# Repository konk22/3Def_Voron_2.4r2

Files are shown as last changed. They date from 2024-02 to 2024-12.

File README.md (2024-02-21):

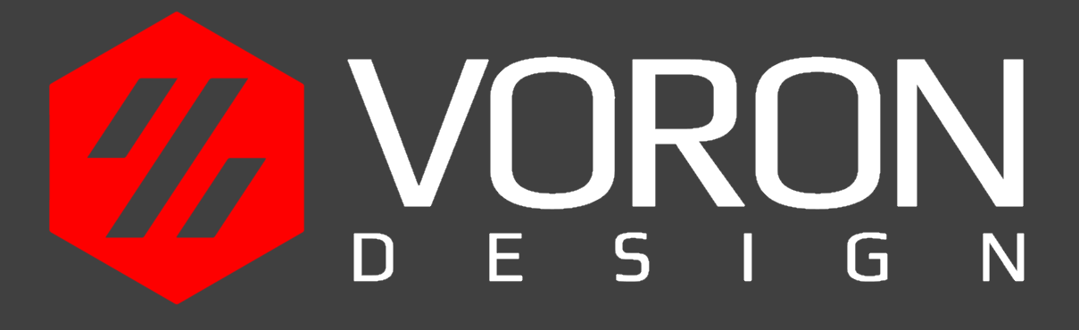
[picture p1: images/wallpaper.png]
  

# Репозиторий является личным сборником систематизированных данных для настройки и доработки принтера Voron 2.4r2 300mm от поставщика 3Def.  
## Все материалы, предоставленные в этом репозитории, являются компиляцией советов, инструкций и примеров конфигураций, полученных из официальных wiki каждого компонента сборки:  

* Комплект для сборки включает в себя:  
	* Voron 2.4r2 300mm;
  	* StealthBurner; 
	* OrangePI Zero 3;  
	* MKS Monster8v2;  
 	* Mellow Fly-SB2040;  
  	* Euclid probe;  
  	* Camera 1080p;  
  	* Display 7 inch, HDMI, LCD 1920x1080, Capacitive Touch Screen;  
  	* BTT Smart Filament Sensor;   
  
* Используемое ПО:  
	* Ubuntu 22.04 jammy server linux6.1.31;
 	* CanBoot;
  	* Klipper;
  	* Mainsail;
  	* KlipperScreen;
  	* Telegram Bot;
  	* Crowsnest;
  	* Mobileraker;
  	* K-ShakeTune  
  
* Дополнения:  
  	* Система очистки сопла;  
  	* Система перемешивания воздуха в камере Nevermore;  
  	* Система вентиляции с угольным фильтром и функции поддержания заданной температуры в камере;

## Исправления, рекомендации, новые подходы к настройке и прочие комментарии прошу оставлять [здесь](https://github.com/konk22/3Def_Voron_2.4r2/discussions/new?category=ideas)

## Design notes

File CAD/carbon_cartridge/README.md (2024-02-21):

# Угольный фильтр для системы вентеляции
* Настройка печати:
  * своев сверху: 0
  * слоев снизу: 0  
  * заполнение: 20%
  * тип заполнения: гироидный  
* После печати необходимо вырезать безворсовую салфетку и проложить ее между прижимом для салфетки и корпусом фильтра, вторую салфетку необходимо проложить между крышкой и вторым прижимом. При необходимости капнуть супер-клей в стык крышки и прижима для салфетки

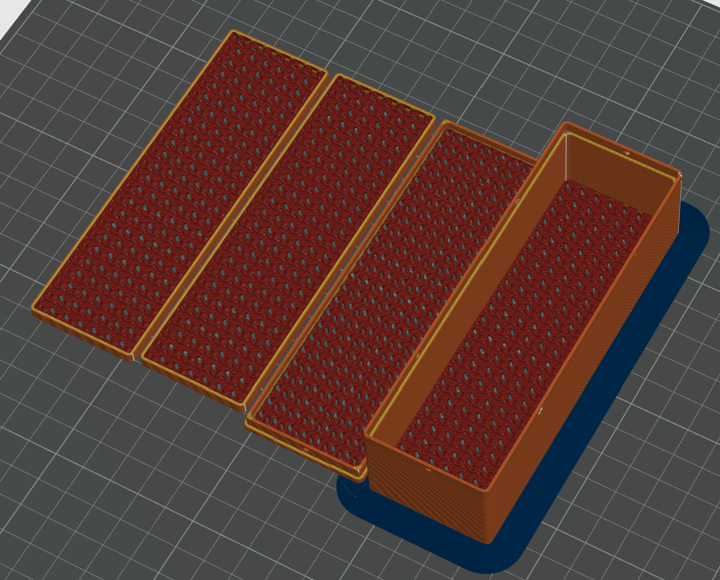
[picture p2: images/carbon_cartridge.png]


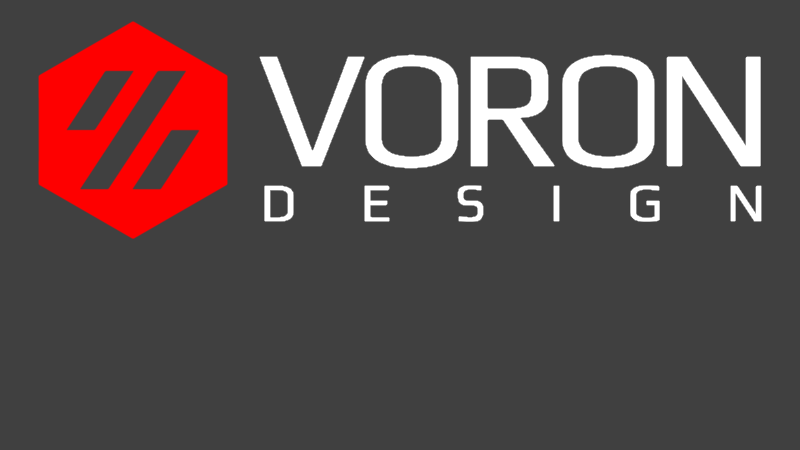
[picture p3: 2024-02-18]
images/watermark800x450.png

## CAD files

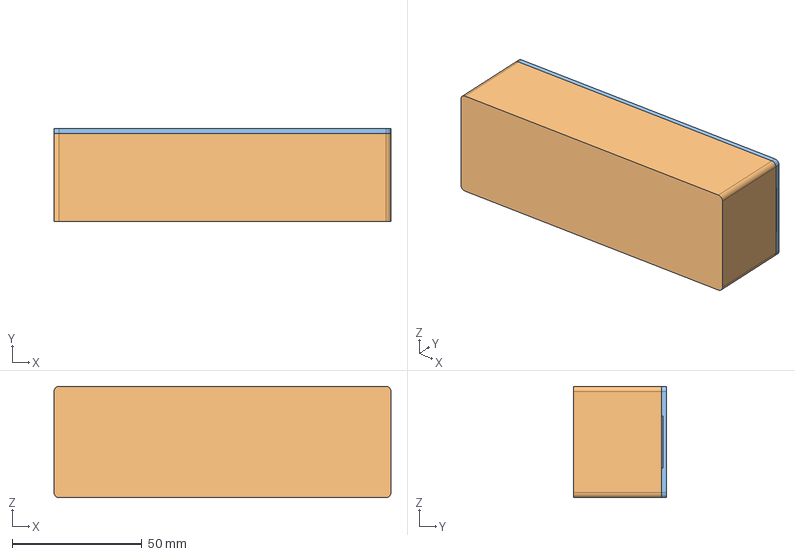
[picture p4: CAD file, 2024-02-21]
CAD/carbon_cartridge/carbon_cartridge.step
130.0 x 36.0 x 43.0 mm
прижим для салфетки
фильтр
Крышка

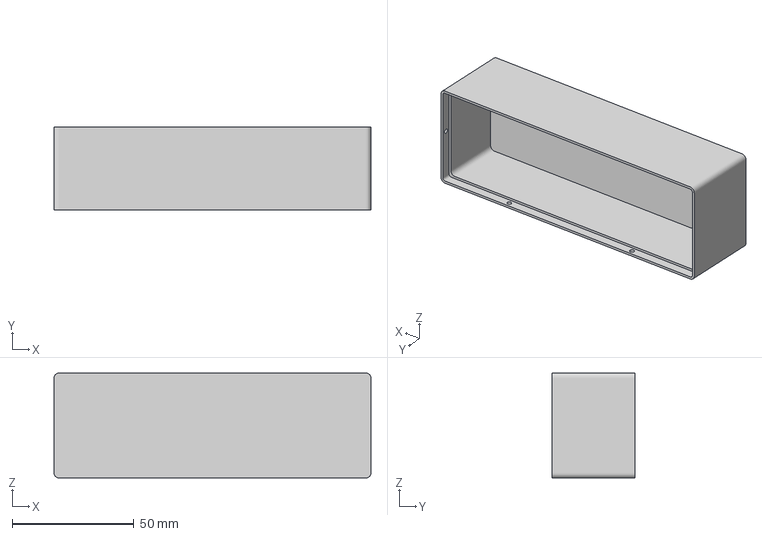
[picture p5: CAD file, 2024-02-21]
CAD/carbon_cartridge/filter.3mf
130.0 x 34.0 x 43.0 mm

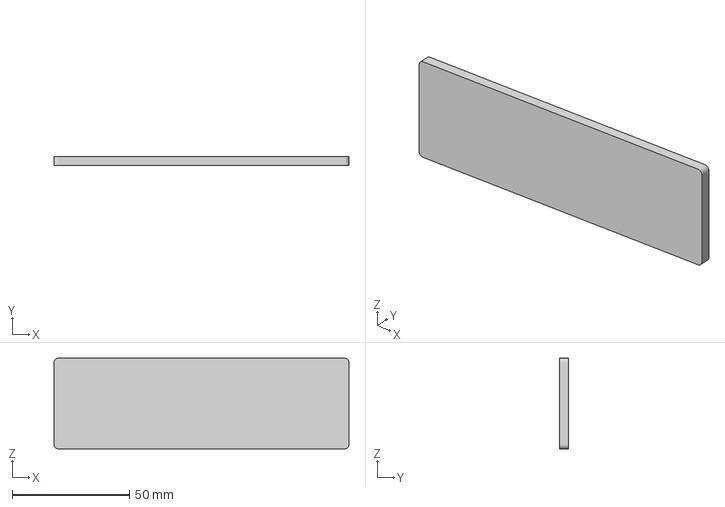
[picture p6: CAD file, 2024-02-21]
CAD/carbon_cartridge/napkin_clamp.3mf
125.6 x 4.00 x 38.6 mm

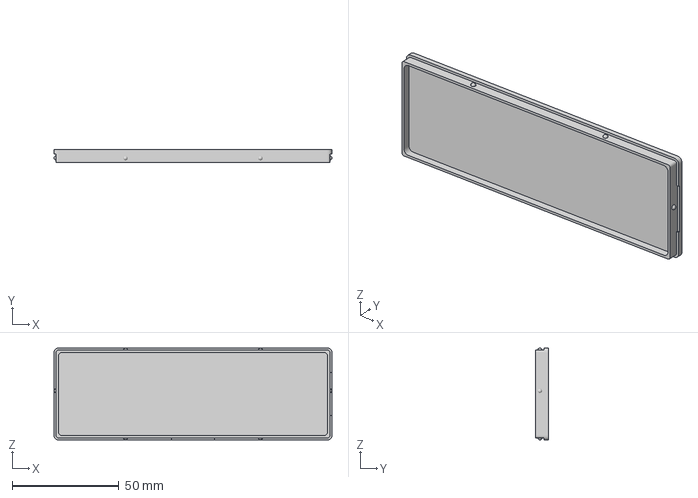
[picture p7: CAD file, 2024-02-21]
CAD/carbon_cartridge/cap.3mf
130.0 x 6.00 x 43.0 mm

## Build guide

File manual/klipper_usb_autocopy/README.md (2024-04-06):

# Klipper USB Autocopy    
This script facilitates the automatic mounting and copying of files from USB drives on a Raspberry Pi system.  

## Functionality  
* **Mounting USB Drives**: When a USB drive is plugged in, the script automatically detects it and mounts it to the system.  
* **Copying Files**: Once mounted, the script identifies specified file patterns (e.g., *.gcode) on the USB drive and copies them to a designated destination directory. If no matching files are found, the script exports files from the destination directory to the USB drive.  
* **Unmounting USB Drives**: When a USB drive is removed, the script unmounts it from the system and removes any associated mount points.  
* **Notification**: Upon completion of the copying process, a short beep is emitted. This requires the "beeper" to be declared in Klipper configuration.    
  
## Installation  
This script can be installed using the install.sh script by executing the following command:  
```  
wget -O - https://raw.githubusercontent.com/konk22/3Def_Voron_2.4r2/main/manual/klipper_usb_autocopy/install.sh | bash
```  
Ensure that you have necessary permissions and review the script before executing it on your system.  

For detailed information on how the script works, refer to the comments within the script file.  

Inspired by the project: https://github.com/DrumClock/mount_copy/tree/main

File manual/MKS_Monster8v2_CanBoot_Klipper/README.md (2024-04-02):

## Установка на MKS Monster8v2 CanBoot и прошивки Klipper:  

* Устанавливаем CanBoot:  
  ```
  cd ~
  git clone https://github.com/Arksine/katapult
  ```  
* Устанавливаем Pyserial:  
  ```
  pip3 install pyserial
  ```  
* Выключаем принтер от сети 220, затем переводим плату MKS Monster8v2 в режим DFU:  
    * Ставим перемычку в блоке "select" (зеленый квадрат, замкнута левая группа контактов);  
    * Ставим перемычку питания платы в положение "On" (красный квадрат, замкнуты верхние контакты);  
    * Подключаем питание Orangepi Zero 3 к внешнему источнику питания, например зарядка для телефона или повербанк. К сети 220 принтер не подключаем!!!  
    * Зажимаем кнопки Reset и Boot. Отпускаем сначала Reset, затем Boot  

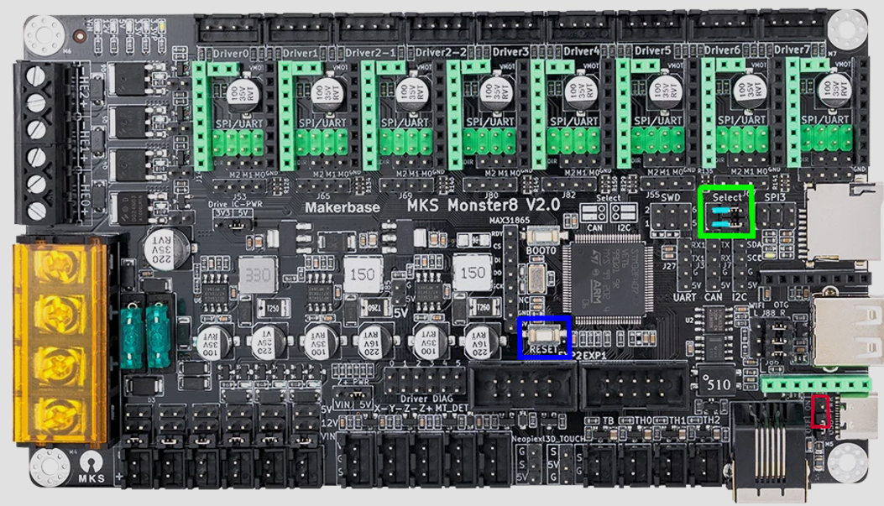
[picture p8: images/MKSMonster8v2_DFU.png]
  
  
* Подключаемся через SSH к Orangepi Zero 3, и проверяем подключился ли MCU. В ответ должны получить ```STMicroelectronics STM Device in DFU mode```:  
    
    
* Компилируем прошивку CanBoot для MKS Monster8v2:  
  ```
  cd katapult
  make menuconfig
  ```  
* Выставляем настройки как на картинке:  

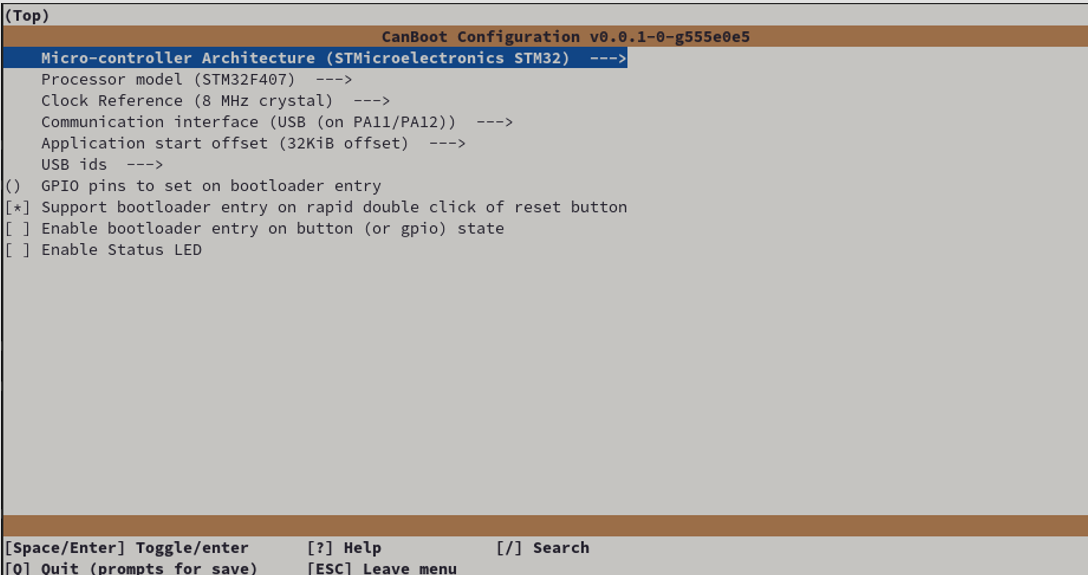
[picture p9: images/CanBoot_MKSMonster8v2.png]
    

* Компилируем:  
  ```
  make clean
  make
  ```  
* Прошиваем CanBoot в MKS Monster8v2. ПРИМЕЧАНИЕ. Если после вышеизложенного вы видите ошибку, не волнуйтесь, все в порядке, если у вас есть надпись «Файл загружен успешно» в строке перед ошибкой:  
  ```
  sudo dfu-util -a 0 -D ~/katapult/out/katapult.bin --dfuse-address 0x08000000:force:mass-erase:leave -d 0483:df11
  ```  
* Проверяем загружен ли CanBoot. Дважды нажимаем Reset, затем вводим команды:  
  ```
  lsusb
  	# в ответ должны получить OpenMoko stm32f407xx
  ls /dev/serial/by-id/
  	# в ответ должны получить серийный номер устройства /dev/serial/by-id/usb-katapult_stm32f407xx_<серийный номер>-if00
  ПРИМЕЧАНИЕ: /dev/serial/by-id/usb-katapult_stm32f407xx_<серийный номер>-if00 необходим для следующих шагов
  ```  
* Компилируем прошивку Klipper для Monster8v2:  
  ```
  cd ~/klipper
  make menuconfig
  ```  
* Выставляем настройки как на картинке:

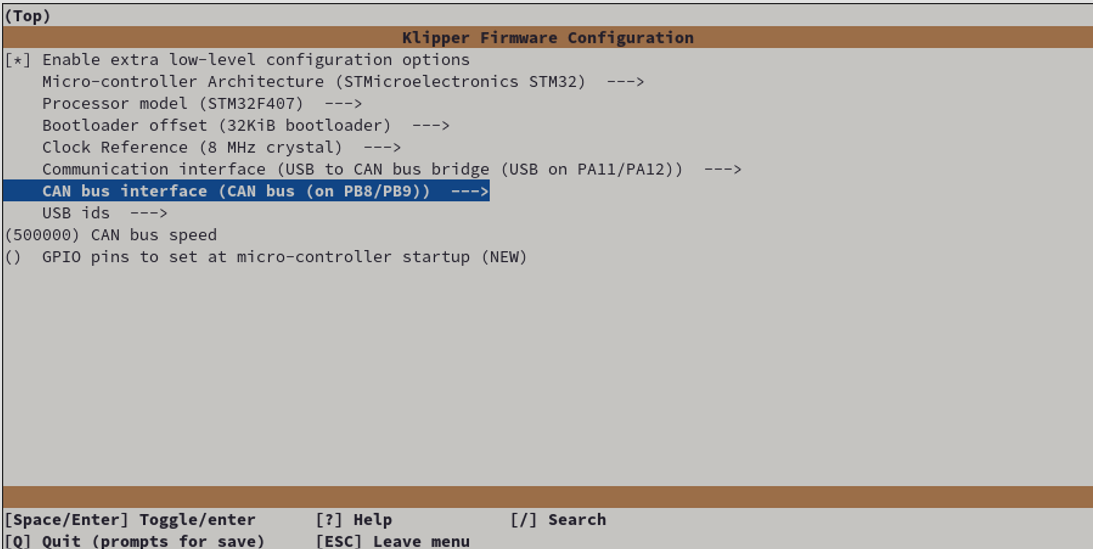
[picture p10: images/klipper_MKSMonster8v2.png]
  
      
* Компилируем:  
  ```
  make clean
  make
  ```  
* Прошиваем MKS Monster8v2 только что скомпилированной прошивкой Klipper через katapult:  
  ```
  python3 ~/katapult/scripts/flash_can.py -d  /dev/serial/by-id/usb-CanBoot_stm32f407xx_<серийный номер>-if00
  ```  

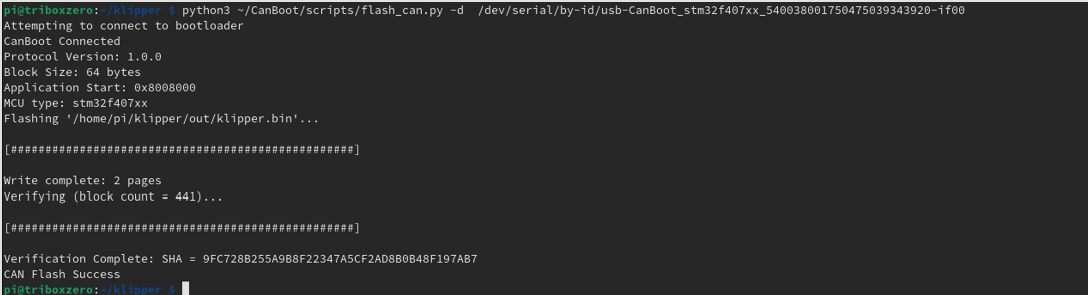
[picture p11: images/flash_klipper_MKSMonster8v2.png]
  
    
* Настраиваем интерфейс CAN0 на Orangepi Zero 3. Создадим файл интерфейса:  
  ```
  sudo nano /etc/network/interfaces.d/can0
  ```  
* Запишем настройки интерфейса в файл:  
  ```
  allow-hotplug can0
  iface can0 can static
	 bitrate 500000
	 up ifconfig $IFACE txqueuelen 256
	 pre-up ip link set can0 type can bitrate 500000
	 pre-up ip link set can0 txqueuelen 256

  ```  
* Перезагружаем:  
  ```
  sudo reboot
  ```  
* Проверяем установлена ли связь с MKS Monster8v2 после прошивки. В ответе должна быть строка с ```1b50:606f OpenMoko```:  
  ```
  lsusb
  ```  

    

* Отключаем внешнее питание от orangepi. Ставим перемычку питания платы в положение "Off" (красный квадрат, замкнуты нижние контакты):  
   
    
  
* Подключаем питание 220 к принтеру и проверяем видит ли Orangepi Zero 3 наш MKS Monster8v2:  
  ```
  ~/katapult/scripts/flash_can.py -i can0 -q
  ```  

    

* Проверяем работает ли интерфейс CAN0:  

    

* Получаем UUID MKS Monster8v2. ПРИМЕЧАНИЕ: Команда возвращает UUID только для неинициализарованных MCU в Klipper (printer.cfg):  
  ```
  ~/katapult/scripts/flash_can.py -i can0 -q
  ```  
    
    
* Для инициализируем MSU в printer.cfg, добавим данные строки:  
  ```
  [mcu]
  canbus_uuid: <ВСТАВИТЬ UUID>
  ```
* Проверяем раздел ```Настройки->Системная информация``` Mainsail. Должен появиться ```mcu (stm32f407xx)```, а так же версии прошивок ```host (aarch64, 64bit)``` и ```mcu (stm32f407xx)``` должны быть одинаковые:  

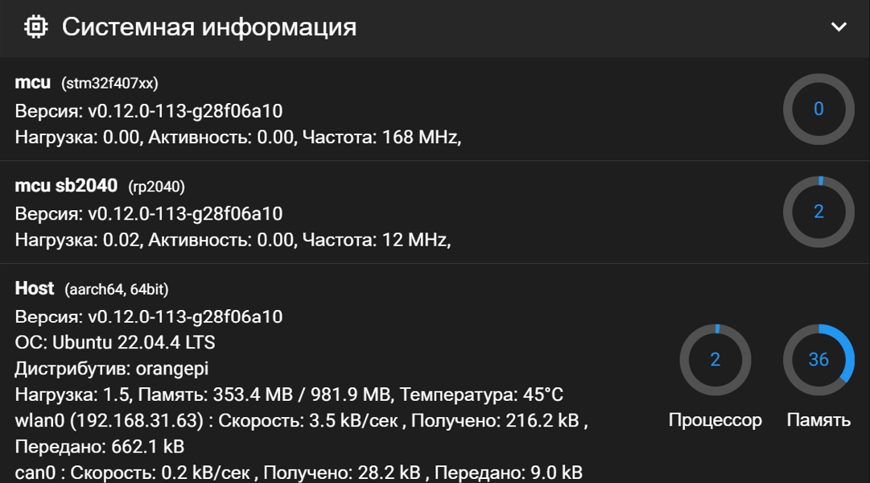
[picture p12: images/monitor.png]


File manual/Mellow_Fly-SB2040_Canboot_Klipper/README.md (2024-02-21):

## Установка CanBoot и прошивка Klipper для Mellow Fly-SB2040:  

* Подготавливаем Mellow Fly-SB2040 к прошивке:  
	* Выключаем принтер от сети 220;  
	* Отключаем CAN проводку от модуля Fly-SB2040;  
	* Подключаем кабель Type-c к порту orangepi Zero 3;  
 	* Подключаем питание 220 к принтеру;  
	* Зажимаем кнопку Boot на Fly-SB2040;  
	* Подключаем провод Type-c к модулю Fly-SB2040 и отпускаем кнопку Boot;  
	* Подключаемся к принтеру по ssh  
* Компилируем прошивку CanBoot для Mellow Fly-SB2040:  
  ```
  cd ~/CanBoot
  make menuconfig
  ```  
* Выставляем настройки как на картинке:  
  
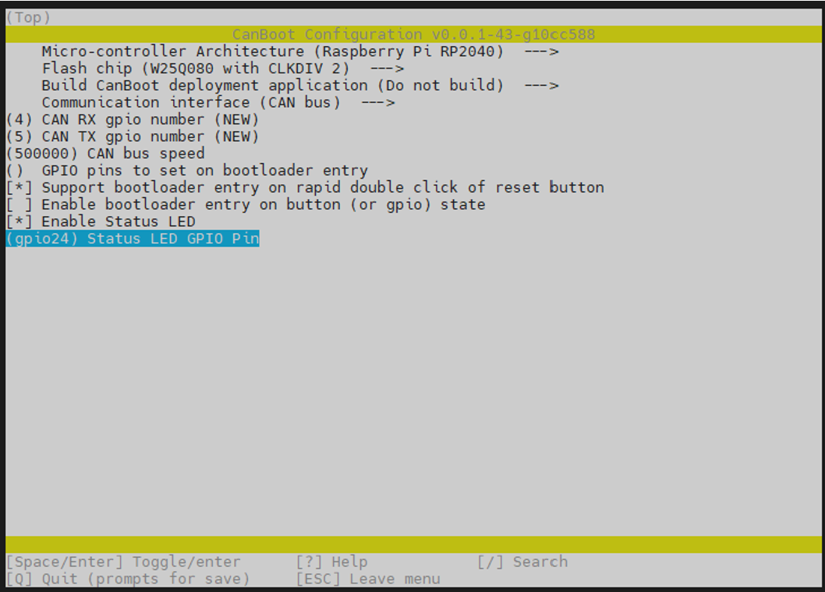
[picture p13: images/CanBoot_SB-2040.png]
  

* Компилируем:  
  ```
  make clean
  make -j4
  ```  
* Проверяем подключение Fly-SB2040 к Orangepi Zero 3. В ответе должна быть строка ```Bus 006 Device 002: ID 2e8a:0003 Raspberry Pi RP2 Boot```:  
  ```
  lsusb
  ```  
* Прошиваем Fly-SB2040 только что скомпилированной прошивкой CanBoot:  
  ```
  cd ~/CanBoot
  make flash FLASH_DEVICE=2e8a:0003
  ```  
* Если не настраивали ранее, то добавляем интерфейс CAN0 на Orangepi Zero 3. Создадим файл интерфейса:  
  ```
  sudo nano /etc/network/interfaces.d/can0
  ```  
* Запишем настройки интерфейса в файл:  
  ```
  allow-hotplug can0
  iface can0 can static
	 bitrate 500000
	 up ifconfig $IFACE txqueuelen 256
	 pre-up ip link set can0 type can bitrate 500000
	 pre-up ip link set can0 txqueuelen 256

  ```  
* Перезагружаем:  
  ```
  sudo reboot
  ```  
* Компилируем прошивку Klipper для Fly-SB2040  
  ```
  cd ~/
  ./kiauh/kiauh.sh
  ```  
* Выставляем настройки как на картинке:  

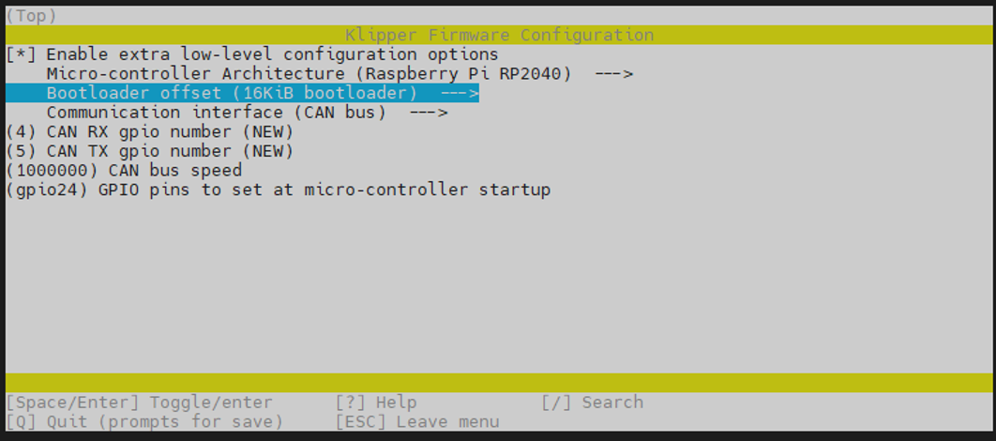
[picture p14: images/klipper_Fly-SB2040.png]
    

* Прошиваем Fly-SB2040 только что скомпилированной прошивкой Klipper. Дожидаемся надписи ```CAN Flash Success ``` как показано на картинке ниже:  
  ```
  python3 ~/klipper/lib/canboot/flash_can.py -u <UUID-Fly-SB2040>
  ```  

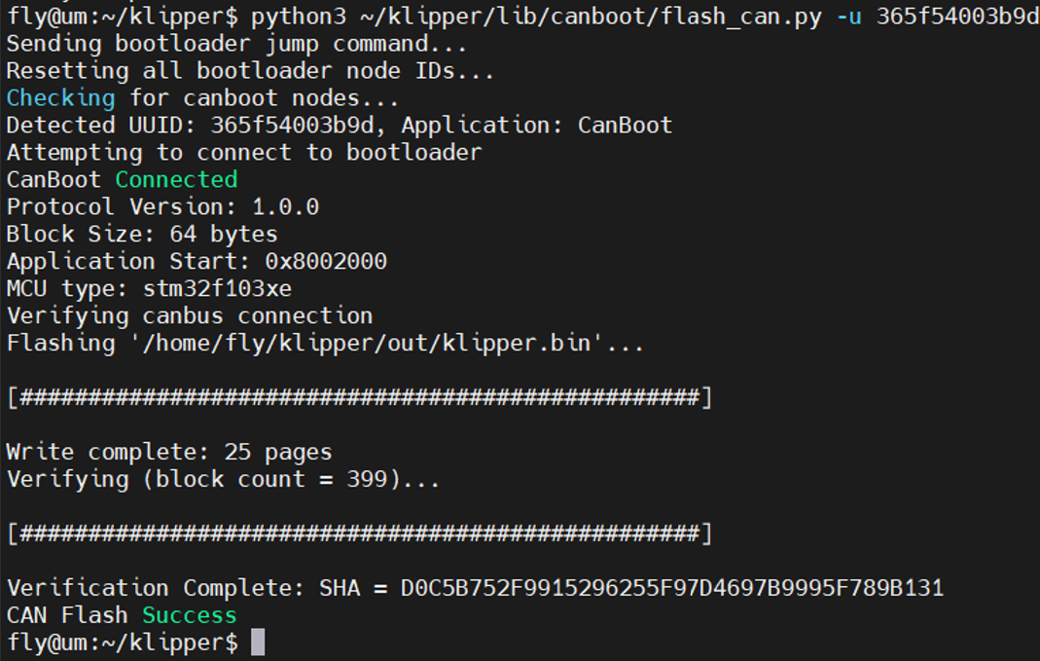
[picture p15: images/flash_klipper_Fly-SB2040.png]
    

* Проверяем раздел ```Настройки->Системная информация``` Mainsail. Должен появиться ```mcu sb2040(rp2040)```, а так же версии прошивок ```host (aarch64, 64bit)``` и ```mcu sb2040(rp2040)``` должны быть одинаковые:    



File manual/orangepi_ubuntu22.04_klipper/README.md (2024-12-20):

# Инструкция по подготовке дистрибутива Ubuntu 22.04 и установке Klipper на Orangepi Zero 3 

* Для установки потребуется скачать дистрибутив Ubuntu 22.04 для Orangepi Zero 3:  
  ```
  http://www.orangepi.org/html/hardWare/computerAndMicrocontrollers/service-and-support/Orange-Pi-Zero-3.html
  ```  
* Записать его на SD карту:  
  * Для Windows: с помощью программы ```Rufus``` или ```BalenaEtcher```  
  * Linux или Mac: ```BalenaEtcher```  
    Подробная инструкция: [KlipperWiki](https://klipper.wiki/ru/home/initial/base#prepare_orange_flash)  
* Установить SD карту в Orangepi Zero 3, подключить клавиатуру и монитор (KlipperScreen HDMI)  
  * Подключаем Orangepi Zero 3 к WIFI.  
        Вводим команду: ```nmtui```  
        Выбираем ```Activate a connections```  
        Подключаемся к своей домашней WIFI сети  
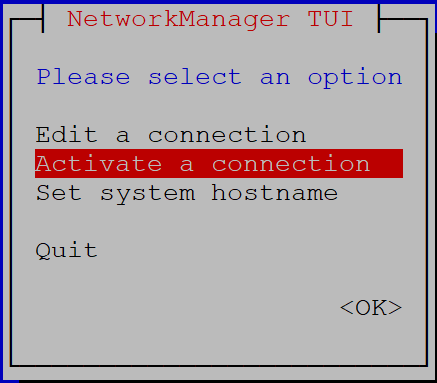
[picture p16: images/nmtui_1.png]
        
    
* Клавиатуру можно отключать, она больше не понадобится  
* Подключаемся к Orangepi Zero 3 по SSH с помощью PuTTY  
* Переходим в пользователя root. Пароль ```orangepi```:  
  ```
  su
  ```  
* Меняем пароль для пользователя root:  
  ```
  passwd
  ```  
* Создаем пользователя ```pi```:  
  ```
  sudo adduser pi
  ```  
* Настраиваем права пользователю аналогично пользователя orangepi:  
  ```
  sudo usermod -aG tty,disk,dialout,sudo,audio,video,plugdev,games,users,systemd-journal,input,netdev pi
  ```  
* Меняем пользователя для автовхода. Меняем ```--autologin orangepi``` на ```--autologin pi```:  
  ```
  sudo nano /lib/systemd/system/getty@.service.d/override.conf
  ```  
* Перезагружаем Orangepi Zero 3. Снова подключаемся через SSH с учетными данными ```pi``` и снова переходим в пользователя root:  
  ```
  reboot
  su
  ```  
* Удаляем пользователя ```orangepi```:  
  ```
  sudo killall -9 -u orangepi && sudo deluser --remove-all-files orangepi
  ```  
* Настраиваем поведение sudo. Меняем строку ```%sudo   ALL=(ALL:ALL) ALL``` на строку ```%sudo   ALL=NOPASSWD: ALL```:  
  ```
  sudo EDITOR=nano visudo
  ```  
* Снова перезагружаем и подключаемся через SSH под пользователем pi:  
  ```
  reboot
  ```  
* Проверяем удален ли пользователь orangepi. Повторяем процедуру удаления если пользователь удален не полностью:  
  ```
  ls /home
  папки orangepi не должно быть в ответе
  su orangepi
  user orangepi does not exist or the user entry does not contain all the required fields
  ```
* Отключим поддержку ipv6:
  ```
  sudo nano /etc/sysctl.conf
  ```
  * Добавим в конец файла:
    ```
    net.ipv6.conf.all.disable_ipv6 = 1
    net.ipv6.conf.default.disable_ipv6 = 1
    net.ipv6.conf.lo.disable_ipv6 = 1
    ```
* Отключим китайские репозитории и добавим глобальные:  
  ```
  sudo nano /etc/apt/sources.list
  ```  
  * Закомментируем все строки и в конец добавим следующее:  
    ```
    deb http://ports.ubuntu.com/ jammy main restricted universe multiverse
    #deb-src http://ports.ubuntu.com/ jammy main restricted universe multiverse
  
    deb http://ports.ubuntu.com/ jammy-security main restricted universe multiverse
    #deb-src http://ports.ubuntu.com/ jammy-security main restricted universe multiverse
  
    deb http://ports.ubuntu.com/ jammy-updates main restricted universe multiverse
    #deb-src http://ports.ubuntu.com/ jammy-updates main restricted universe multiverse
  
    deb http://ports.ubuntu.com/ jammy-backports main restricted universe multiverse
    #deb-src http://ports.ubuntu.com/ jammy-backports main restricted universe multiverse
    ```  
* Отключим китайский репозиторий docker. Закомментируем все записи в файле:  
  ```
  sudo nano /etc/apt/sources.list.d/docker.list
  ```  
* Добавим глобальный репозиторий docker:  
  ```
  sudo curl -fsSL https://download.docker.com/linux/ubuntu/gpg -o /etc/apt/keyrings/docker.asc
  sudo chmod a+r /etc/apt/keyrings/docker.asc
  echo \
  "deb [arch=$(dpkg --print-architecture) signed-by=/etc/apt/keyrings/docker.asc] https://download.docker.com/linux/ubuntu \
  $(. /etc/os-release && echo "$VERSION_CODENAME") stable" | \
  sudo tee /etc/apt/sources.list.d/docker.list > /dev/null
  ```  
* Обновим систему. Ошибок и предупреждений не должно быть:  
  ```
  sudo apt update && sudo apt dist-upgrade -y
  ```  
* Установим пакеты необходимые для работы KlipperScreen:  
  ```
  sudo apt install xorg xinit xserver-xorg-legacy libjpeg-dev zlib1g-dev python3-pip python3-dev libatlas-base-dev python3-gi-cairo python3-virtualenv gir1.2-gtk-3.0 virtualenv matchbox-keyboard wireless-tools xdotool xinput x11-xserver-utils libopenjp2-7 python3-distutils python3-gi python3-setuptools python3-wheel python3-can
  pip3 install vext
  pip3 install vext.gi
  ```  
* Меняем имя хоста. Я выбрал имя ```Voron```:  
  ```
  hostnamectl set-hostname Voron
  ```  
* Удаляем логотип загрузки Ubuntu:  
  ```
  sudo rm /usr/share/plymouth/themes/spinner/bgrt-fallback.png
  sudo rm /usr/share/plymouth/ubuntu-logo.png
  ```  
* Подготавливаем свой логотип в формате png с прозрачным фоном, размер 800x450, изображение должно быть немного выше середины картинки, или копируем логотип из предложенного примера в домашнюю директорию, а затем перемещаем в директорию темы по умолчанию:  
  ```
  sudo wget https://raw.githubusercontent.com/konk22/3Def_Voron_2.4r2/main/images/watermark800x450.png 
  sudo cp /home/pi/watermark800x450.png /usr/share/plymouth/themes/spinner/watermark.png
  ```  
* Копируем логотип загрузки системы в директорию plymouth:  
  ```
  sudo cp /home/pi/watermark800x450.png /usr/share/plymouth/ubuntu-logo.png
  ```  
* Обновим конфигурацию Plymouth и initramfs:  
  ```
  sudo update-initramfs -u
  ```  
* Если в процессе загрузки Orangepi Zero 3 необходимо увидеть лог загрузки, то необходимо на клавиатуре нажать F8.  
* Включим boot splash screen. Необходимо заменить ```bootlogo=false``` на ```bootlogo=true``` и в конец файла добавить строку ```extraargs="console=tty3 consoleblank=0 loglevel=1 quiet splash"```:  
  ```
  sudo nano /boot/orangepiEnv.txt
  ```  
* Для правильной работы KlipperScreen необходимо добавить следующую строку в конфиг xorg:  
  ```
  sudo bash -c "echo needs_root_rights=yes>>/etc/X11/Xwrapper.config"
  ```
* Отключаем ненужные службы для ускорения загрузки. ПРИМЕЧАНИЕ: если используется bluetooth, то ```bluetooth.service``` необходимо удалить из команд:
  ```
  sudo apt-get remove networkd-dispatcher
  sudo systemctl stop systemd-networkd.service dnsmasq.service lircd.service containerd.service bluetooth.service
  sudo systemctl disable systemd-networkd.service dnsmasq.service lircd.service containerd.service bluetooth.service
  ```  
* Перезагружаем:  
  ```
  sudo reboot
  ```  
* Установим git:  
  ```
  sudo apt-get update && sudo apt-get install git -y
  ```  
* Скачиваем Kiauh и переходим в директорию Kiauh:  
  ```
  cd ~ && git clone https://github.com/dw-0/kiauh.git
  ```
* Запускаем скрипт Kiauh:  
  ```
  ./kiauh/kiauh.sh
  ```  
* Вас встретит следующее окно. Нажимаем ```1```, затем устанавливаем по очереди: Klipper, Moonraker, Mainsail, KlipperScreen, Telegram Bot, Crowsnest, Mobileraker:  
   
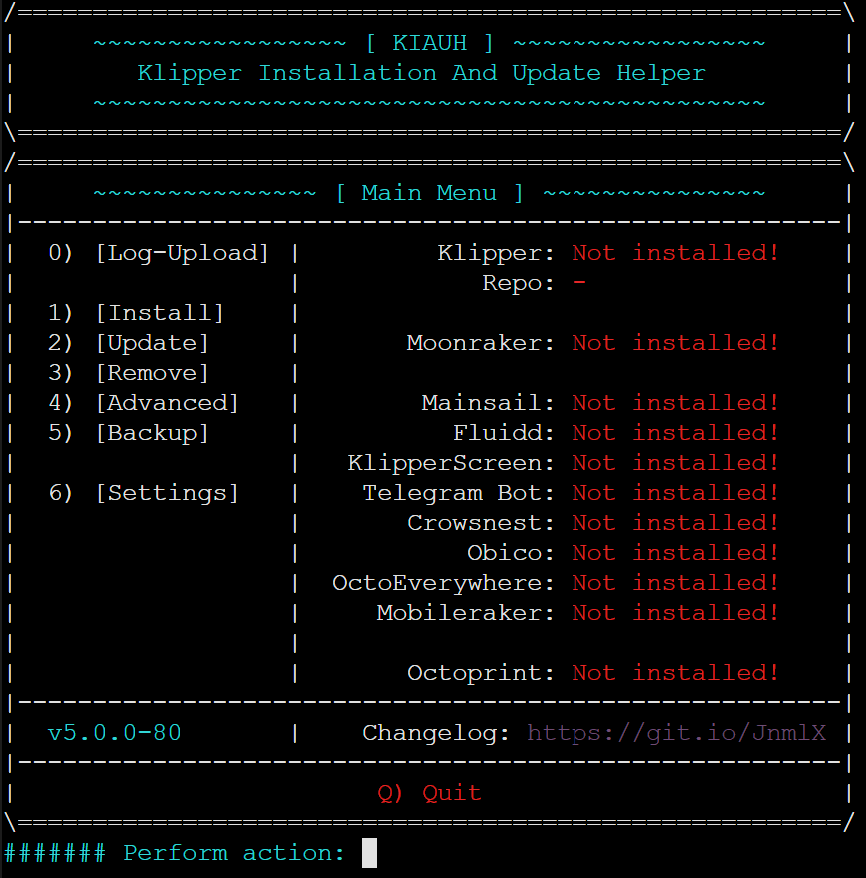
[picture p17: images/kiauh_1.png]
    
    
    
    
* После установки всех пакетов нажимаем ```B``` и выходим на начальное окно. Оно должно выглядеть так:  
    
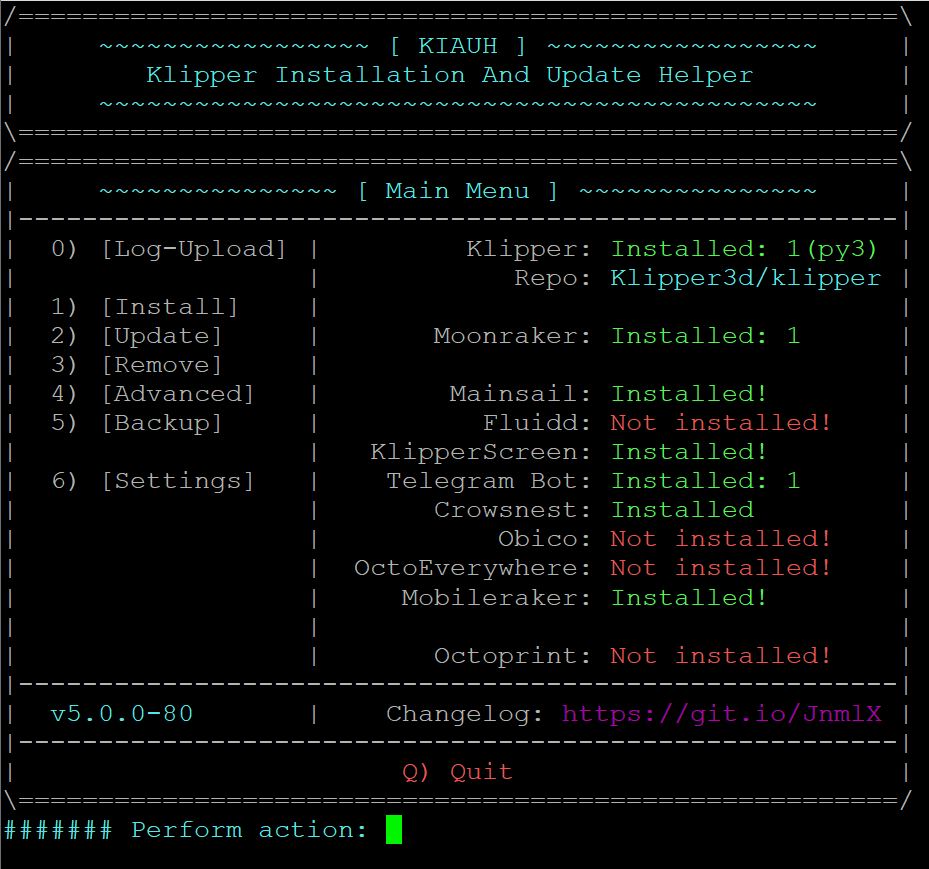
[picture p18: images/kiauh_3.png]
    

* Теперь устанавливаем K-ShakeTune:
  ```
  wget -O - https://raw.githubusercontent.com/Frix-x/klippain-shaketune/main/install.sh | bash
  ```
* Когда будет создан файл конфига ```print.cfg``` в начало файла необходимо будет добавить:
  ```
  [shaketune]
  # result_folder: ~/printer_data/config/ShakeTune_results
  #    The folder where the results will be stored. It will be created if it doesn't exist.
  # number_of_results_to_keep: 3
  #    The number of results to keep in the result_folder. The oldest results will
  #    be automatically deleted after each runs.
  # keep_raw_csv: False
  #    If True, the raw CSV files will be kept in the result_folder alongside the
  #    PNG graphs. If False, they will be deleted and only the graphs will be kept.
  # show_macros_in_webui: True
  #    Mainsail and Fluidd doesn't create buttons for "system" macros that are not in the
  #    printer.cfg file. If you want to see the macros in the webui, set this to True.
  # timeout: 300
  #    The maximum time in seconds to let Shake&Tune process the CSV files and generate the graphs.
  ```
    
## На этом подготовка дистрибутива Ubuntu и установка Klipper завершена.

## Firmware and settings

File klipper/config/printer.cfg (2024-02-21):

# See docs/Config_Reference.md for a description of parameters.

[include mainsail.cfg]
[include timelapse.cfg]
[include nozzle_scrub.cfg]
[include stealthburner_leds.cfg]
[include offmodule.cfg]
[include duanliaojiance.cfg]
[include ./klicky/klicky-probe.cfg]
[include adxl345.cfg]
[include K-ShakeTune/*.cfg]


[mcu]								# UUID MKS Monster8v2
canbus_uuid: abb4c4e89d2c

[mcu sb2040]						# UUID Mellow Fly-SB2040v2
canbus_uuid: d8f259ee39a2

[virtual_sdcard]                    # Включаем виртуальную SD карту
path: ~/printer_data/gcodes

[temperature_sensor Fly-CAN]		# Создание объекта датчика температуры Mellow Fly-SB2040v2
sensor_type: temperature_mcu
sensor_mcu: sb2040

[temperature_sensor OrangePI]		# Создание объекта датчика температуры OrangePI
sensor_type: temperature_host
#sensor_path: /sys/class/thermal/thermal_zone0/temp
min_temp: -50
max_temp: 100


#--------------------------------------------------------------------
##--------------------------------------------------------------------
[printer]
kinematics: corexy           
max_velocity: 400            
max_accel: 16000              
max_accel_to_decel: 8000     
max_z_velocity: 20           
max_z_accel: 350             
square_corner_velocity: 5.0 


#####################################################################
#                     Мотор оси X
#####################################################################
[stepper_x]
step_pin: PC14                #
dir_pin:  !PC13               #
enable_pin: !PC15             #
rotation_distance: 40         #
microsteps: 16                #
full_steps_per_rotation:200   #
endstop_pin: ^sb2040:gpio29   #
position_min: 0               #
position_endstop: 303         # 
position_max: 303             # 
homing_speed: 180             #
homing_retract_dist: 5        #
homing_positive_dir: true     #

#--------------------------------------------------------------------
[tmc2209 stepper_x]
uart_pin: PE6                 # 
interpolate: false            # 
run_current: 0.8              # 
hold_current: 0.6             # 
sense_resistor: 0.110         # 
#stealthchop_threshold: 200   # 

#####################################################################
#                  Мотор оси Y 
#####################################################################
[stepper_y]
step_pin: PE5                 #
dir_pin: PE4                  #
enable_pin: !PC15             #
rotation_distance: 40         #
microsteps: 16                #
full_steps_per_rotation:200   #
endstop_pin: ^PA15            #
position_min: 0               #
position_endstop: 307         #
position_max: 307             #
homing_speed: 180             #
homing_retract_dist: 5        #
homing_positive_dir: true     #
#--------------------------------------------------------------------
[tmc2209 stepper_y]
uart_pin: PE3                 #
interpolate: false            #
run_current: 0.8              #
hold_current: 0.6             #
sense_resistor: 0.110         #
#stealthchop_threshold: 200   #

#####################################################################
#                           Мотор Z0 - Передний левый
#####################################################################
[stepper_z]
step_pin: PE1                 #
dir_pin: !PE0                 #
enable_pin: !PE2              #
rotation_distance: 40         #
gear_ratio: 80:16             #
microsteps: 16                #
endstop_pin: probe:z_virtual_endstop            #
position_max: 280             #
position_min: -5              #
homing_speed: 10              #
second_homing_speed: 3        #
homing_retract_dist: 3        #
[tmc2209 stepper_z]
uart_pin: PB7                 #
interpolate: false            #
run_current: 0.65             #
hold_current: 0.5             #
sense_resistor: 0.110         #
stealthchop_threshold: 200 #
#--------------------------------------------------------------------
##	Мотор Z1 - задний левый
[stepper_z1]
step_pin: PD6                 #
dir_pin: !PD5                 #
enable_pin: !PD7              #
rotation_distance: 40         #
gear_ratio: 80:16             #
microsteps: 16                #
[tmc2209 stepper_z1]
uart_pin: PD4                 #
interpolate: false            #
run_current: 0.65             #
hold_current: 0.5             #
sense_resistor: 0.110         #
stealthchop_threshold: 200    #
#--------------------------------------------------------------------
##	Мотор Z2 - задний правый 
[stepper_z2]
step_pin: PD2                 #
dir_pin: PD1                  #
enable_pin: !PD3              #
rotation_distance: 40         #
gear_ratio: 80:16             #
microsteps: 16                #
[tmc2209 stepper_z2]
uart_pin: PD0                 #
interpolate: false            #
run_current: 0.65             #
hold_current: 0.5             #
sense_resistor: 0.110         #
stealthchop_threshold: 200    #
#--------------------------------------------------------------------
##	Мотор Z3 - передний правый 
[stepper_z3]
step_pin: PC7                 #
dir_pin: !PC6                 #
enable_pin: !PC8              #
rotation_distance: 40         #
gear_ratio: 80:16             #
microsteps: 16                #
[tmc2209 stepper_z3]
uart_pin: PD15                #
interpolate: false            #
run_current: 0.65             #
hold_current: 0.5             #
sense_resistor: 0.110         #
stealthchop_threshold: 200    #

[extruder]
step_pin: sb2040:gpio9         #
dir_pin: !sb2040:gpio10        #
enable_pin: !sb2040:gpio7      #
rotation_distance: 23.206     #
gear_ratio: 50:10             #
microsteps: 16                #
full_steps_per_rotation: 200  #
nozzle_diameter: 0.400        #
filament_diameter: 1.75       #
heater_pin:  sb2040:gpio6     #
sensor_type: EPCOS 100K B57560G104F    #Тип датчика температуры  (EPCOS 100K B57560G104F)
sensor_pin: sb2040:gpio27     #
min_temp: -50                 #
max_temp: 330                 #
max_power: 1.0                #
min_extrude_temp: 170         #
max_extrude_only_distance: 200  #
max_extrude_cross_section: 50  #
#control = pid
#pid_kp = 26.213
#pid_ki = 1.304
#pid_kd = 131.721
pressure_advance: 0.078        #
pressure_advance_smooth_time: 0.040    #
[tmc2209 extruder]
uart_pin: sb2040:gpio8         #
interpolate: false             #
run_current: 0.55              #
#hold_current: 0.4             #
sense_resistor: 0.110          #
#stealthchop_threshold: 999999 #

#####################################################################
[verify_heater extruder]      #
max_error: 120                #
check_gain_time:120           #
hysteresis: 50                #
heating_gain: 2               #

#####################################################################
#                            Нагреватель стола
#####################################################################
[heater_bed]
heater_pin: PB10             #
sensor_type: EPCOS 100K B57560G104F   #
sensor_pin: PC0              #
max_power: 1.0               #
min_temp: -70                #
max_temp: 120                #
#control: pid
#pid_kp: 58.437
#pid_ki: 2.347
#pid_kd: 363.769


#####################################################################
#                             Настройка вентеляторов
######################### Охлаждение хотенда ########################
[heater_fan HotendFan]
pin: sb2040:gpio14
max_power: 1.0
kick_start_time: 0.5
heater: extruder
heater_temp: 50.0
fan_speed: 1   #
shutdown_speed: 1.0
######################## Обдув модели ########################
[fan]
pin: sb2040:gpio13
kick_start_time: 0.75
max_power: 1.0

######################## Nevermore ########################
[duplicate_pin_override]
pins: PC0                 #
[temperature_fan Nevermore]
pin: PB0
max_power: 1       #
shutdown_speed: 0.0
kick_start_time: 5.0
sensor_type: EPCOS 100K B57560G104F
sensor_pin: PC0
min_temp: -70     #
max_temp: 130     #
target_temp: 110  #
gcode_id: A
control: watermark

########################  Вытяжка #########################
[temperature_fan Вытяжка]
pin: PA3
max_power: 1
shutdown_speed: 0.0
kick_start_time: 5.0
sensor_type: ATC Semitec 104GT-2
sensor_pin: sb2040:gpio26
min_temp: -70     #
max_temp: 85      #
target_temp: 64   #
gcode_id: C
control: watermark

########################  Подвал#########################
[temperature_fan Подвал]
pin: PA0
max_power: 1      #
shutdown_speed: 0.0
kick_start_time: 5.0
sensor_type: temperature_mcu
#sensor_pin: 
min_temp: -70
max_temp: 100
target_temp: 40    #
gcode_id: D
control: watermark

#####################################################################
#	Управление LED
#####################################################################
[neopixel Корпус]
pin: PA8
chain_count: 50
color_order: GRB
initial_RED: 1
initial_GREEN: 1
initial_BLUE: 1
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

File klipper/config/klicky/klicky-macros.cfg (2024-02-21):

# This macro was provided by discord user Garrettwp to whom i give my thanks for sharing it with me.
# I have tweaked it a lot.
# They are based on the great Annex magprobe dockable probe macros "#Originally developed by Mental,
# modified for better use on K-series printers by RyanG and Trails", kudos to them.
# That macro as since evolved into a klipper plugin that currently is pending inclusion in klipper,
# more information here, https://github.com/Annex-Engineering/Quickdraw_Probe/tree/main/Klipper_Macros
# User richardjm revised the macro variables and added some functions
# User sporkus added led status notifications
# Thanks to all who helped,
# by standing on the shoulders of giants, lets see if we can see further
#
# the current home for this version is https://github.com/jlas1/Klicky-Probe

[respond]

[gcode_macro _Probe_Variables]
variable_probe_attached:            False
variable_probe_state:               False
variable_probe_lock:                False
variable_z_endstop_x:               0
variable_z_endstop_y:               0
gcode:


#checks if the variable definitions are up to date
[gcode_macro _klicky_check_variables_version]
gcode:
    {% set version = printer["gcode_macro _User_Variables"].version|default(0) %}

    {% if version != 1 %}
        { action_raise_error("Please update your klicky variables, there are some functionality changes") }
    {% endif %}

[gcode_macro _KlickyDebug]
gcode:
    {% set message  = params.MSG %}
    {% set debug = printer["gcode_macro _User_Variables"].debug|default(False) %}

    {% if debug %}
        { action_respond_info(message) }
    {% endif %}


[gcode_macro _exit_point]
gcode:
    {% set function  = 'pre_' ~ params.FUNCTION %}
    {% set move  = params.MOVE|default(0) %}
    {% set speed = printer["gcode_macro _User_Variables"].travel_speed %}

    # mandatory to save the new safe position
    M400
    SET_VELOCITY_LIMIT ACCEL={printer.configfile.settings.printer.max_accel}
    SET_VELOCITY_LIMIT ACCEL_TO_DECEL={printer.configfile.settings.printer.max_accel_to_decel}
    RESTORE_GCODE_STATE NAME={function} MOVE={move} MOVE_SPEED={speed}


[gcode_macro _entry_point]
gcode:
    {% set function  = 'pre_' ~ params.FUNCTION %}
    {% set move_accel = printer["gcode_macro _User_Variables"].move_accel|default(1000) %}
    # mandatory to save the new safe position
    M400
    SAVE_GCODE_STATE NAME={function}
    # removes the Z offset for better bed based docking
    SET_GCODE_OFFSET Z=0
    # all the macros initially assume absolute positioning
    G90
    # set a safe(sane) Acceleration
    SET_VELOCITY_LIMIT ACCEL={move_accel}

[gcode_macro _Homing_Variables]
gcode:
    {% set reset  = params.RESET|default(0) %}
    {% if reset %}
        SET_GCODE_VARIABLE MACRO=_Probe_Variables VARIABLE=probe_lock VALUE={ False }
    {% endif %}

##########################
# Attach probe and lock it
[gcode_macro Attach_Probe_Lock]
description: Attaches Klicky Probe, can only be docked after unlocking
gcode:
    Attach_Probe
    _Probe_Lock

########################
# Dock probe and lock it
[gcode_macro Dock_Probe_Unlock]
description: Docks Klicky Probe even if it was locked
gcode:
    _Probe_Unlock
    Dock_Probe

##############
# Unlock Probe
[gcode_macro _Probe_Unlock]
description: Unlocks Klicky Probe state
gcode:
    _KlickyDebug msg="_Probe_Lock setting probe_lock variable to False"
    SET_GCODE_VARIABLE MACRO=_Probe_Variables VARIABLE=probe_lock VALUE={ False }

############
# Lock Probe
[gcode_macro _Probe_Lock]
description: Locks Klicky Probe state
gcode:
    _KlickyDebug msg="_Probe_Lock setting probe_lock variable to True"
    SET_GCODE_VARIABLE MACRO=_Probe_Variables VARIABLE=probe_lock VALUE={ True }

###################
# Klicky Dock Servo Deploy

[gcode_macro _DeployKlickyDock]
description: Deploys Klicky servo-controlled dock
gcode:
    {% set enable_dock_servo = printer["gcode_macro _User_Variables"].enable_dock_servo|default(False) %}
    {% set servo_delay = printer["gcode_macro _User_Variables"].servo_delay|default(1000) %}
    {% set servo_name = printer["gcode_macro _User_Variables"].servo_name %}
    {% set servo_deploy = printer["gcode_macro _User_Variables"].servo_deploy|default(360) %}

    #wait for all the moves to complete
    M400
    {% if enable_dock_servo != False %}
        _KlickyDebug msg="_DeployKlickyDock Klicky servo configuration enabled"
        {% if servo_deploy == 360 %}
            { action_raise_error("Klicky: servo active on klicky-variables, but no servo deploy angle specified") }
        {% endif %}
        _KlickyDebug msg="_DeployKlickyDock SET_SERVO SERVO={servo_name|string} ANGLE={servo_deploy|int}"
        SET_SERVO SERVO={servo_name|string} ANGLE={servo_deploy|int}
        M400
        G4 P{servo_delay|int}
        _KlickyDebug msg="_DeployKlickyDock SET_SERVO SERVO={servo_name|string} WIDTH=0"
        SET_SERVO SERVO={servo_name|string} WIDTH=0
    {% elif printer["gcode_macro _DeployDock"] is defined %}
        _KlickyDebug msg="_DeployKlickyDock calling _DeployDock"
        _DeployDock
    {% endif %}

####################
# Dock Servo Retract

[gcode_macro _RetractKlickyDock]
description: Retracts Klicky servo-controlled dock
gcode:
    {% set enable_dock_servo = printer["gcode_macro _User_Variables"].enable_dock_servo|default(False) %}
    {% set servo_delay = printer["gcode_macro _User_Variables"].servo_delay|default(1000) %}
    {% set servo_name = printer["gcode_macro _User_Variables"].servo_name %}
    {% set servo_retract = printer["gcode_macro _User_Variables"].servo_retract|default(360) %}

    #wait for all the moves to complete
    M400
    {% if enable_dock_servo != False %}
        _KlickyDebug msg="_RetractKlickyDock Klicky servo configuration enabled"
        {% if servo_retract == 360 %}
            { action_raise_error("Klicky: servo active on klicky-variables, but no servo retract angle specified") }
        {% endif %}
        _KlickyDebug msg="_RetractKlickyDock SET_SERVO SERVO={servo_name|string} ANGLE={servo_retract|int}"
        SET_SERVO SERVO={servo_name|string} ANGLE={servo_retract|int}
        M400
        G4 P{servo_delay|int}
        _KlickyDebug msg="_RetractKlickyDock SET_SERVO SERVO={servo_name|string} WIDTH=0"
        SET_SERVO SERVO={servo_name|string} WIDTH=0
    {% elif printer["gcode_macro _RetractDock"] is defined %}
        _KlickyDebug msg="_RetractKlickyDock calling _RetractDock"
        _RetractDock
    {% endif %}
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

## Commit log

2024-02-18 boot splash screen Voron Design
    For KlipperScreen
2024-04-04 Create mountcopy
2024-04-06 Update mountcopy
